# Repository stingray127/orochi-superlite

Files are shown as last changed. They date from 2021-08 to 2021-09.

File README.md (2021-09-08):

# orochi-superlite
A clean weight reduction mod for the Razer Orochi v2.

Massive props to Razer for releasing such a good mouse!

If you liked or used this design, consider supporting me here: https://www.buymeacoffee.com/stingray127

## Background

The goal of this mod was to nondestructively reduce the weight of the mouse while maintaining functionality and structural integrity.

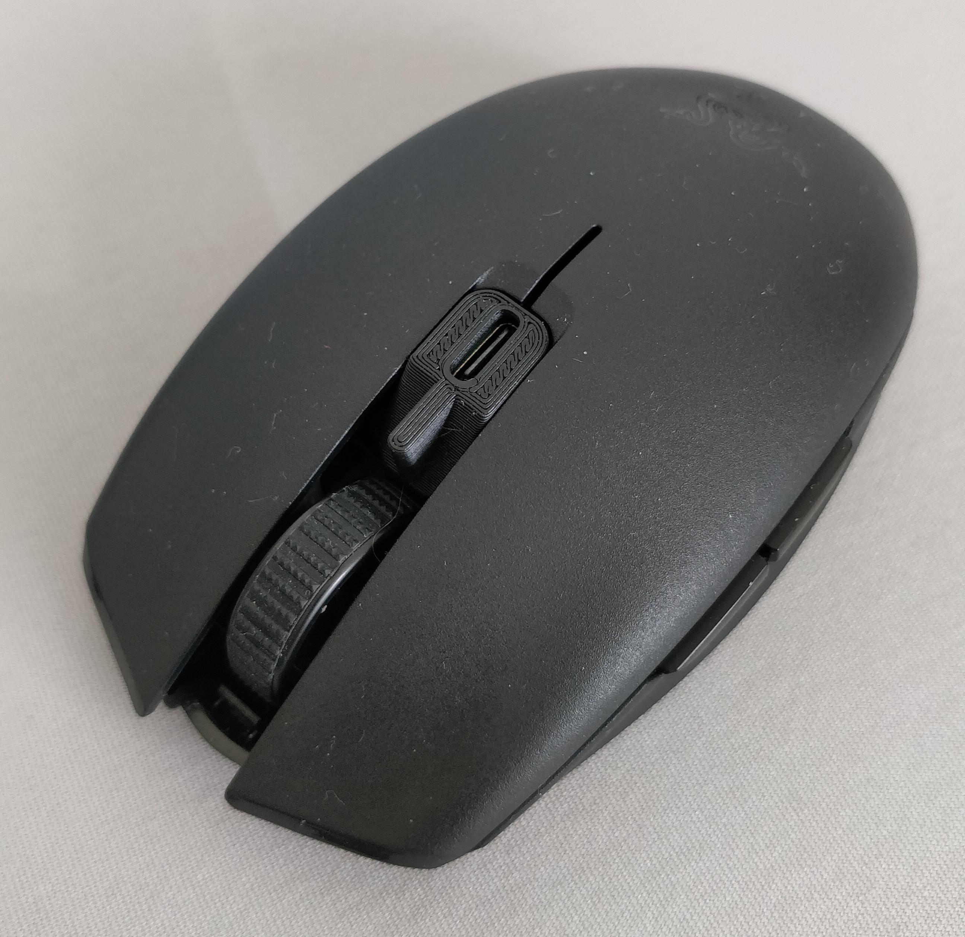
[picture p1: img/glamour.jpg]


The stock mouse is made of 3 main parts: Lower Shell, Upper Shell, and Inner Skeleton.

I removed the Inner Skeleton of the mouse and replaced all its functions with various 3D printed parts.

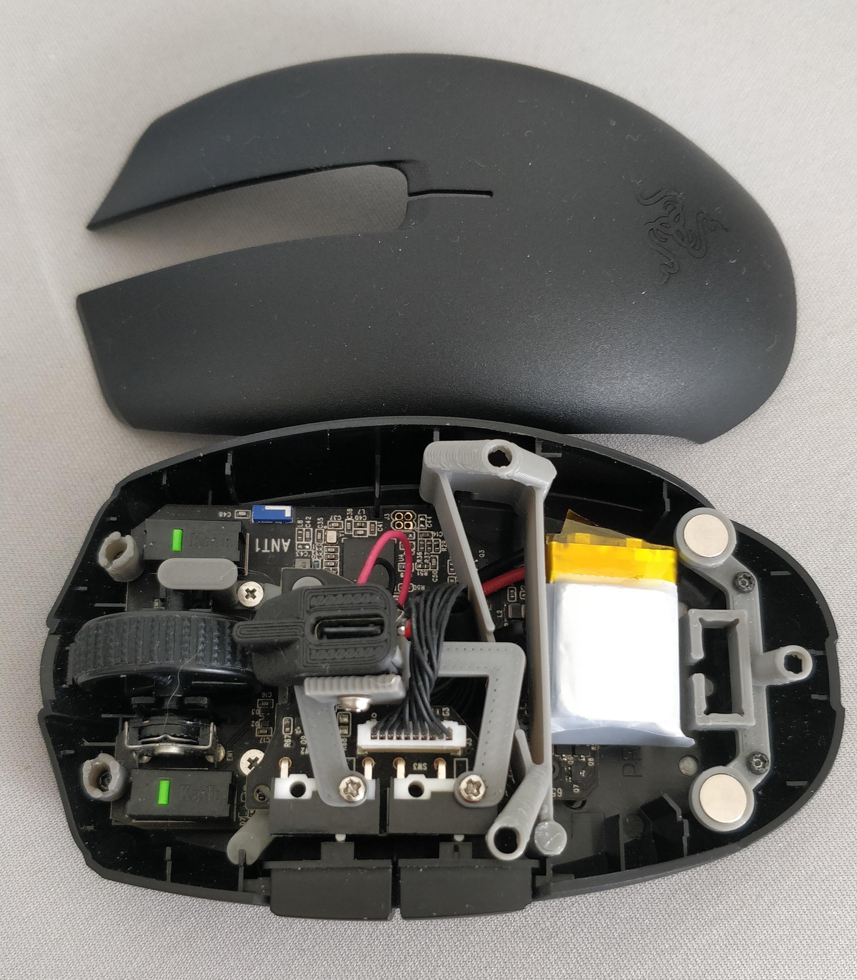
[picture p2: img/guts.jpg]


The final weight of the mouse fully assembled is ~56 grams.

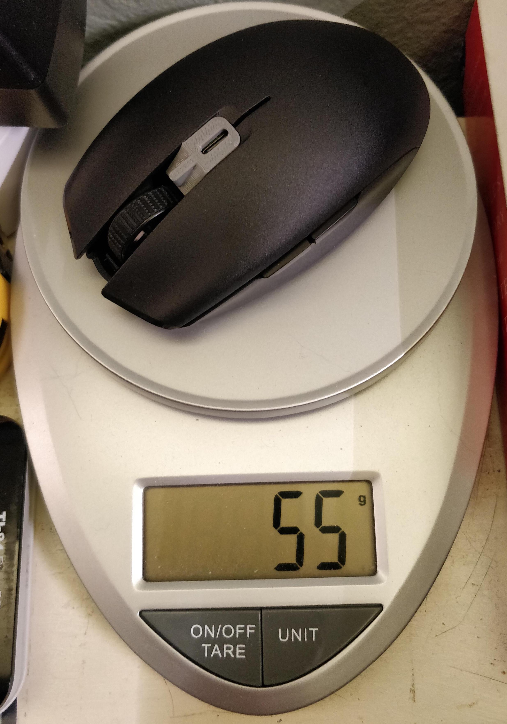
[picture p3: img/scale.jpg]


This image shows the correct orientation for printing each part. Add supports as you see fit.

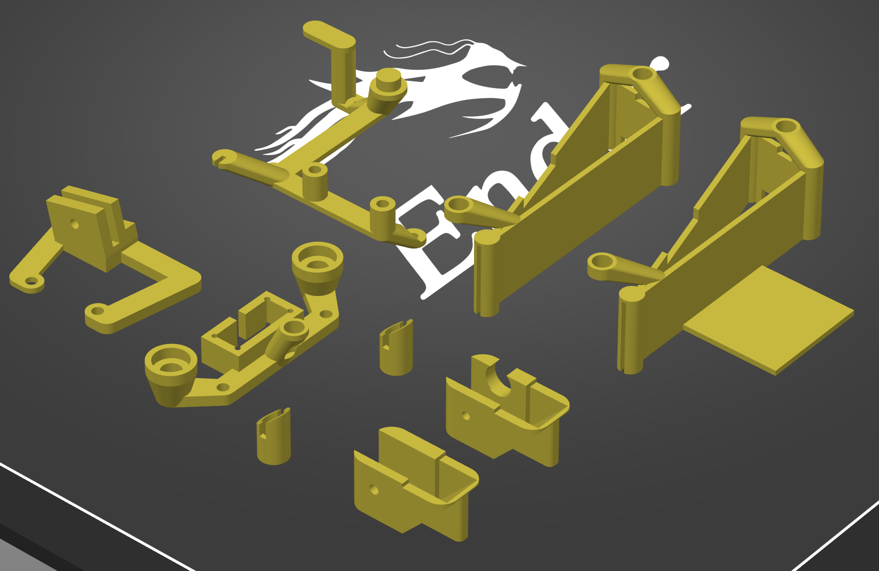
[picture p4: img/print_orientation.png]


Pros:
- Significant weight reduction through the removal of a 14g inner hull.
- 150mah Lipo Power System, significantly lighter than an AA battery.
- USB-C rechargable, charges in ~40 min, lasts 50 hrs.
- Still structurally integral
- Uses original outer shells, so it looks stock and feels nice
- Charging port integrates nondestrucively with the rest of the mouse
- DPI button is moved to a nicer place, can be rebound to an in game function

Cons:
- Still can't use the mouse while charging. The charging circuit only allows usage OR charging, one at a time.
- Depending on what material you print with, the magnet holder might become looser over time (material creep). If the magnet pops out, it can be glued back in.
- It's still an Orochi v2, so the shape is not for everyone.

## Suggested Usage

I don't really recommend going for the Lipo variant unless you really know what you are doing. I had to crack a Lipo AA battery apart to harvest its charging circuit, which should be done with extreme caution. I also directly soldered Lipo connections to the charging circuit, but you could also just source and solder a battery connection to the circuit.

LR44 or 675 Button cells are much safer to work with. Get or print a button cell holder, and desolder the battery cable from the Inner Skeleton part of the stock Orochi, and you're in business.

<!-- ## Functional Descriptions

botscaffold:
- Prevents the scroll wheel from popping up
- Holds the daughterboard in place so the side buttons are usable
- Provides anchor points for topscaffold

anticrush:
- Prevents the user from crushing the walls of the Lower Shell inwards
- Provides 2 indexing points for the Upper Shell

magnetandindexing:
- Keeps the top shell on using the same magnet attachment system as the stock mouse
- Provide a third indexing point for the Upper Shell

cannoli:
- Limits the amount of post travel for clicks
- Prevents Upper Shell from popping off during hard presses of the mouse buttons (top shell used to pop every time I tried to spray transfer)

rhino:
- Holds the charging circuit I used in the lipo variant of the mod
- Acts as a dpi button

topscaffold:
- Puts the rhino at the right location
- Flexes when pressure is applied on the rhino horn to press the DPI button on the daughterboard -->

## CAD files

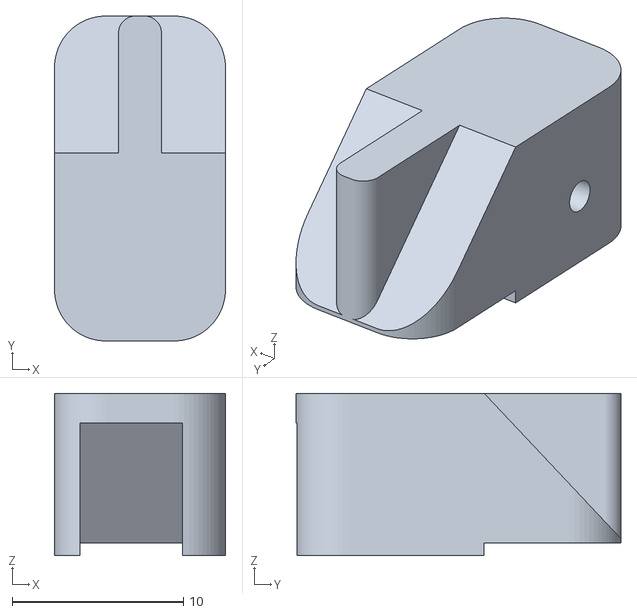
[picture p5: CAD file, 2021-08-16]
stl/rhino_no_usbc.stl
10.0 x 19.0 x 9.50

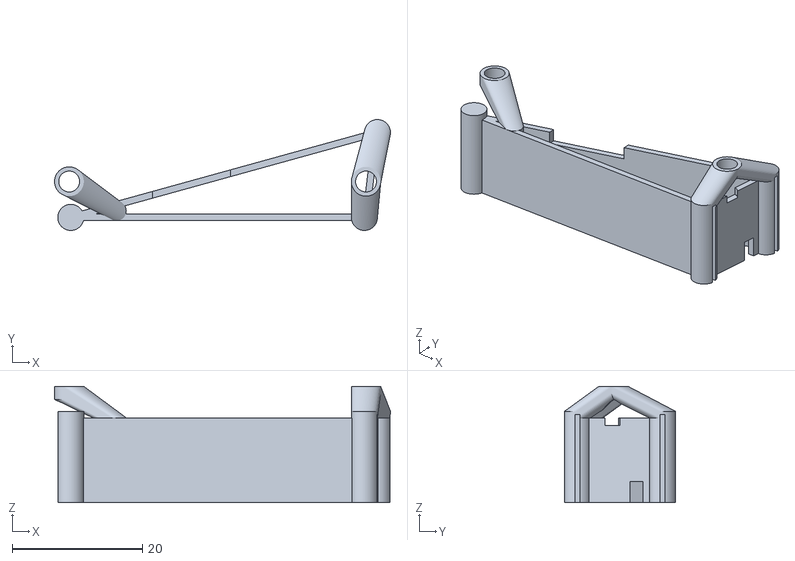
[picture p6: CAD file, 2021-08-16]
stl/anticrush_no_battshelf.stl
51.5 x 17.0 x 17.8

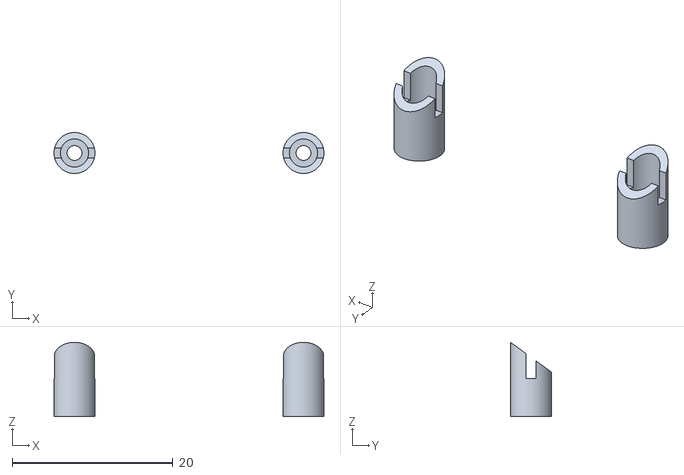
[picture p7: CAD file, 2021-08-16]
stl/cannoli.stl
33.6 x 5.10 x 9.26

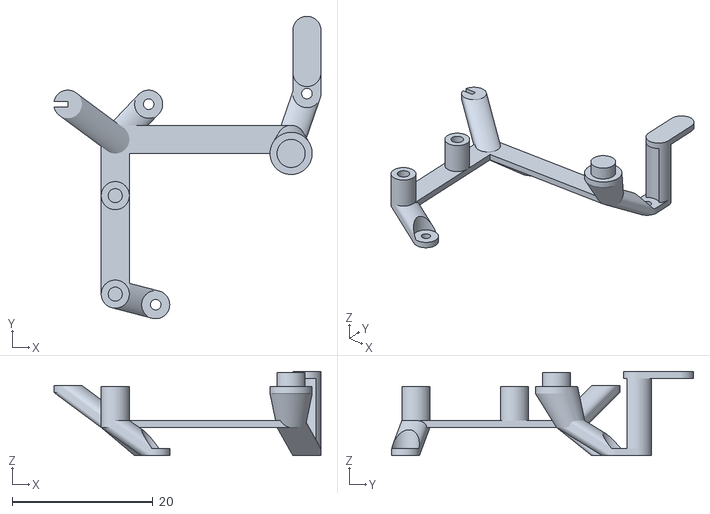
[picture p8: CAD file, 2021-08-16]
stl/botscaffold.stl
38.0 x 43.0 x 12.0

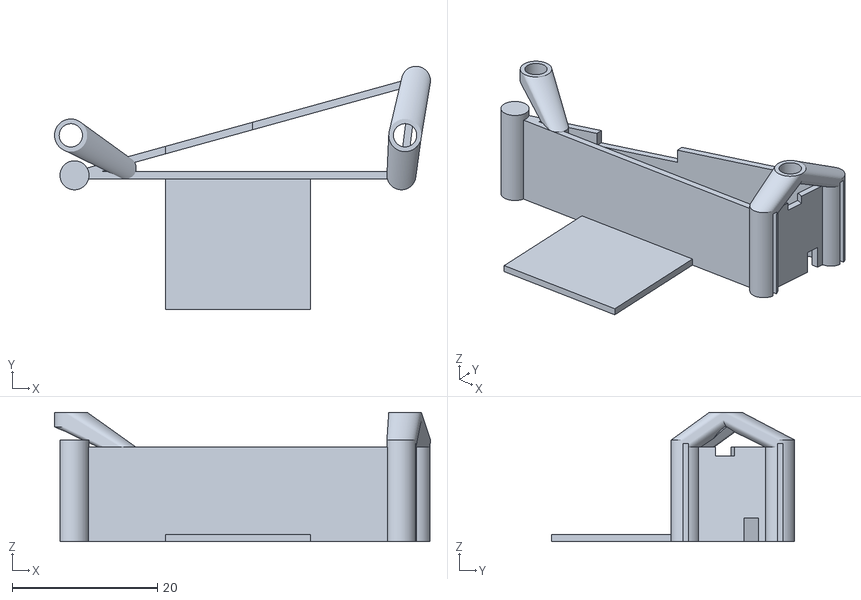
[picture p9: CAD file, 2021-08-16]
stl/anticrush.stl
51.8 x 33.5 x 17.8

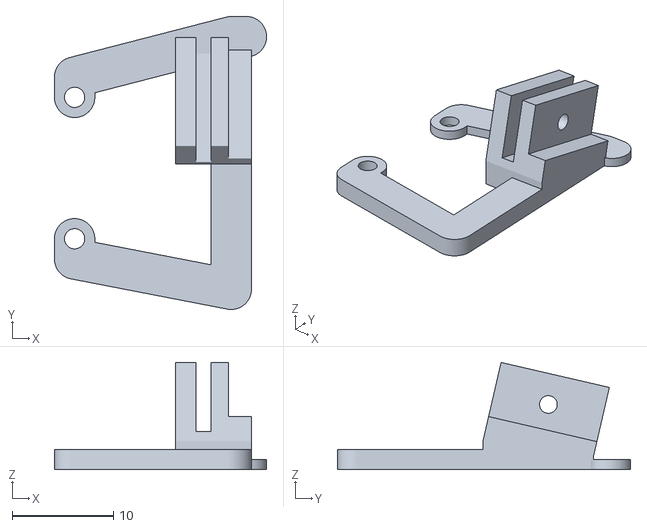
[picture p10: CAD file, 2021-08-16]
stl/topscaffold.stl
21.0 x 29.0 x 10.6

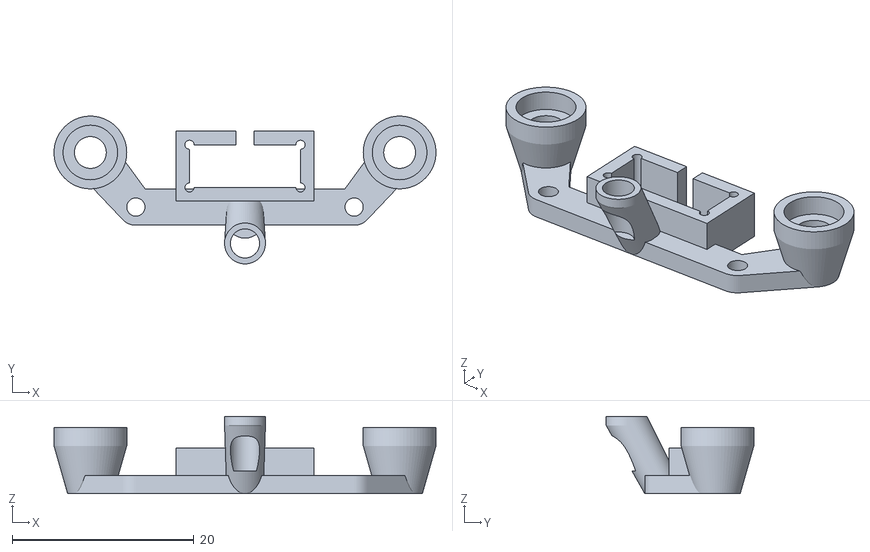
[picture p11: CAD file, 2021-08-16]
stl/magnetAndIndexing.stl
42.0 x 16.2 x 8.50

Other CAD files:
stl/rhino.stl
